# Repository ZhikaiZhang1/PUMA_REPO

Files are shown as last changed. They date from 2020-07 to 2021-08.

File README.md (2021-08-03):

# PUMA_REPO
6 dof robot arm with PD+Gravity control, matlab robot model includes inertia, coriolis and gravity matrix using E-L derivation
See playlist for robot in action and the progress so far:
https://www.youtube.com/watch?v=c_6ysLYgEvc&list=PL2PABLYC7PDOqciOI-CmroK_Q2sk5stWQ&index=1

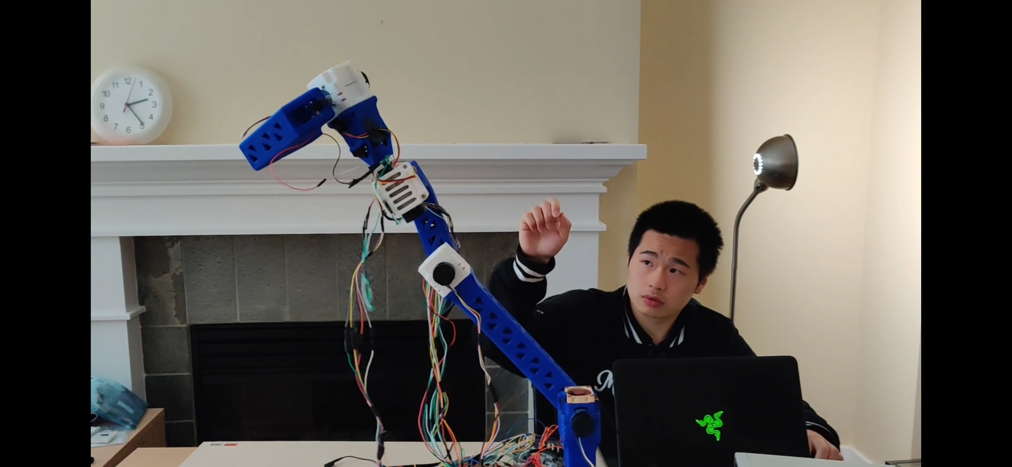
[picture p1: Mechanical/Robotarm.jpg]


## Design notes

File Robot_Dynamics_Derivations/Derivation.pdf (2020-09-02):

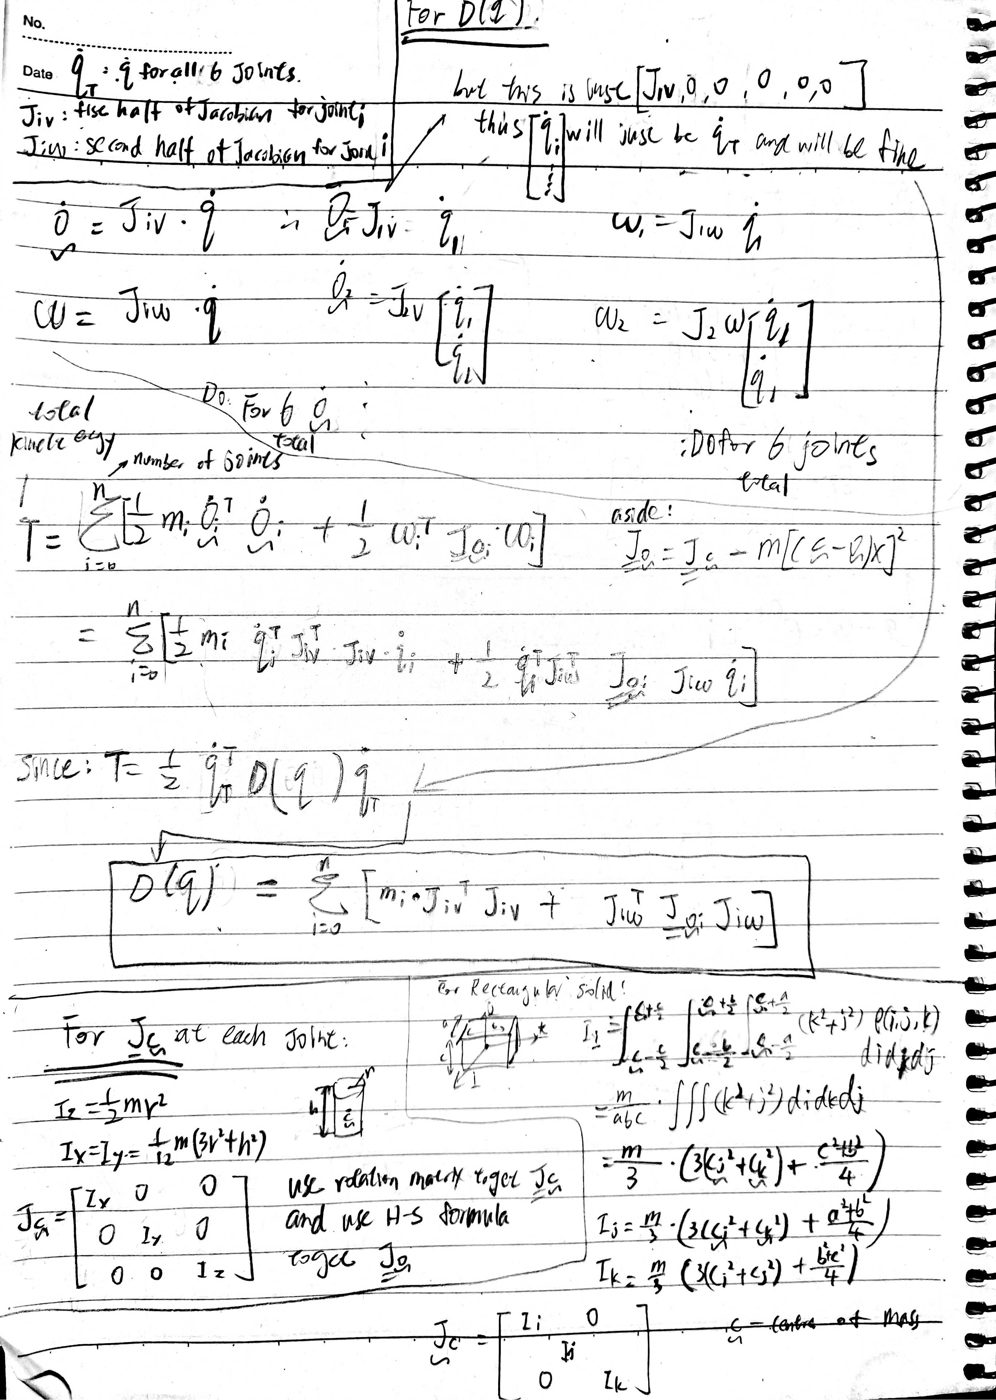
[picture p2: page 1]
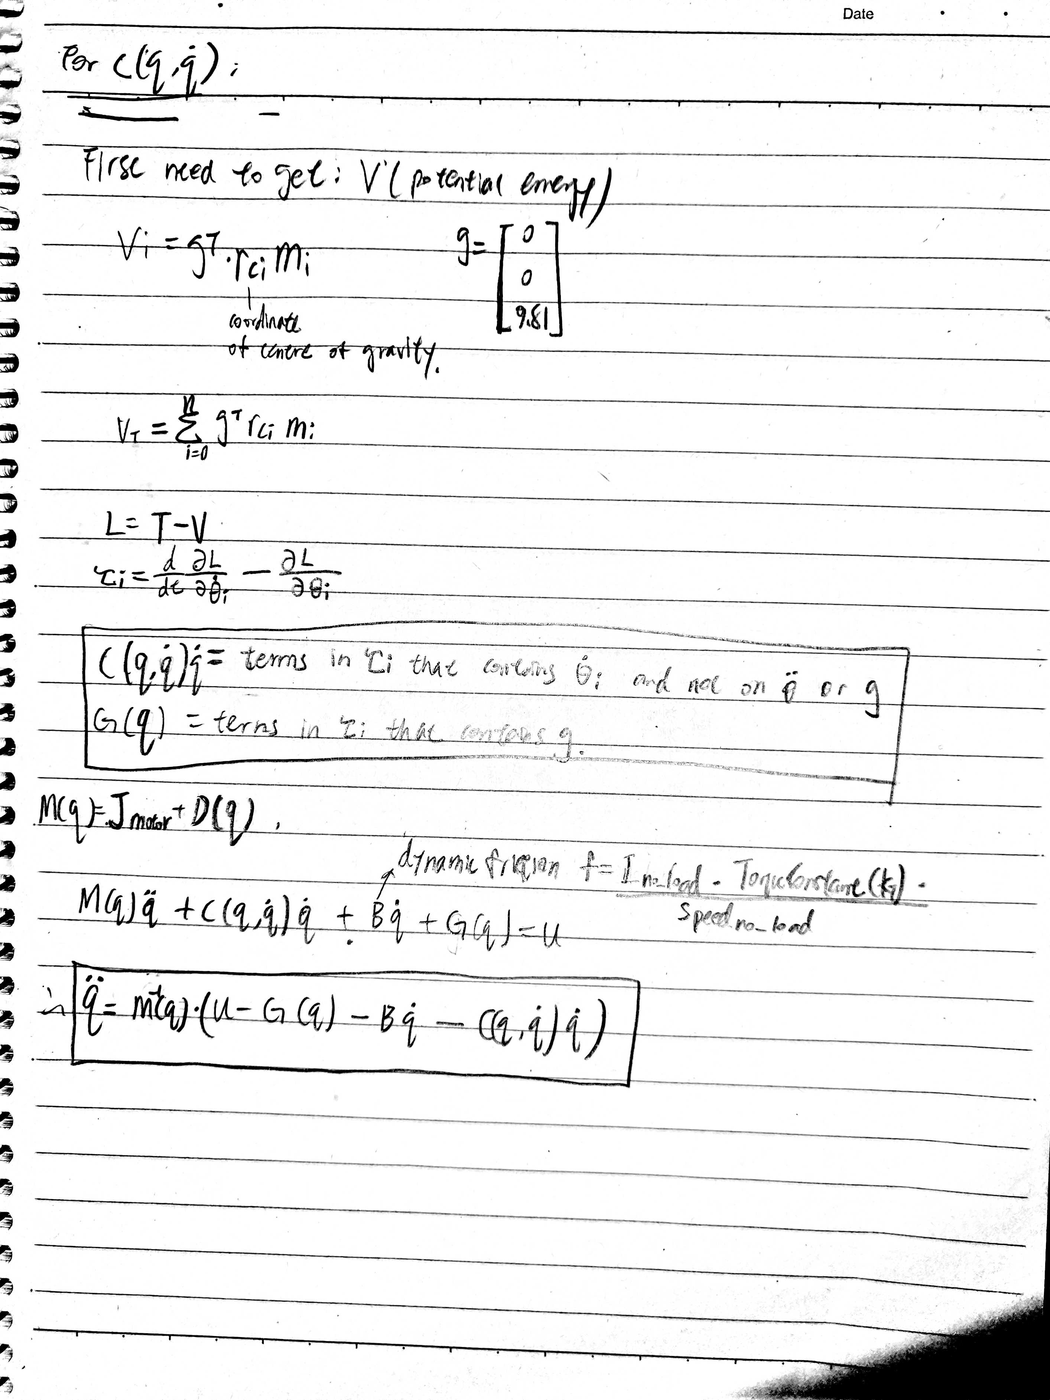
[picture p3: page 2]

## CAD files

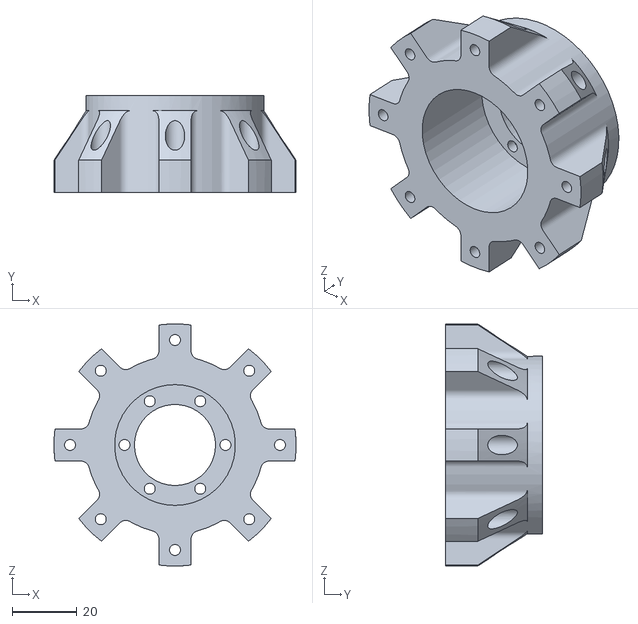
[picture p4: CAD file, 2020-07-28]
Mechanical/Motor_Mounting_Bracket_Top_2.STL
74.9 x 30.0 x 74.9

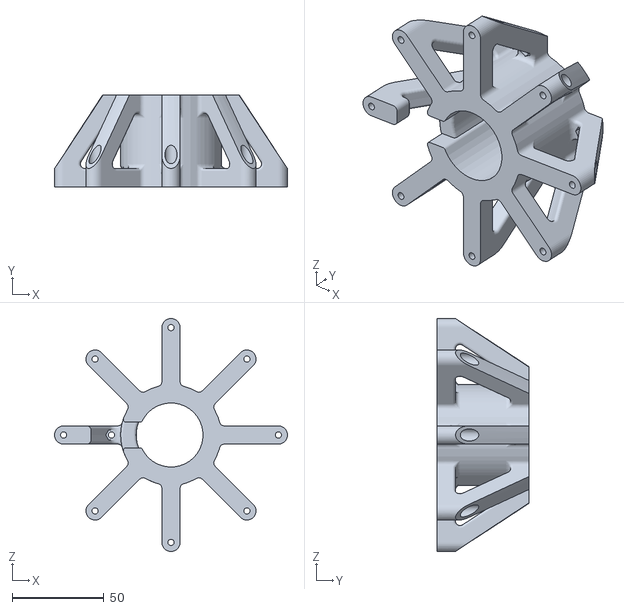
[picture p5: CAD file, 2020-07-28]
Mechanical/Motor_Mounting_Bracket_Bottom_2.STL
127.3 x 50.0 x 127.3

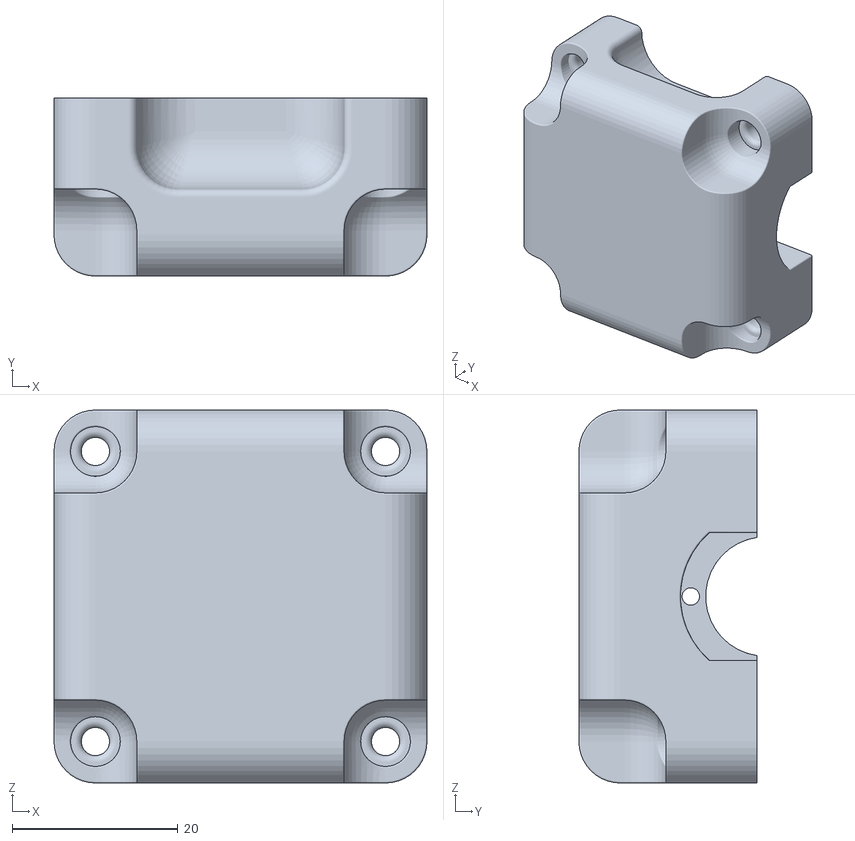
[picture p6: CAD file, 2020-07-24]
Mechanical/Arm 5 - Motor#6 Left.STL
45.0 x 21.5 x 45.0

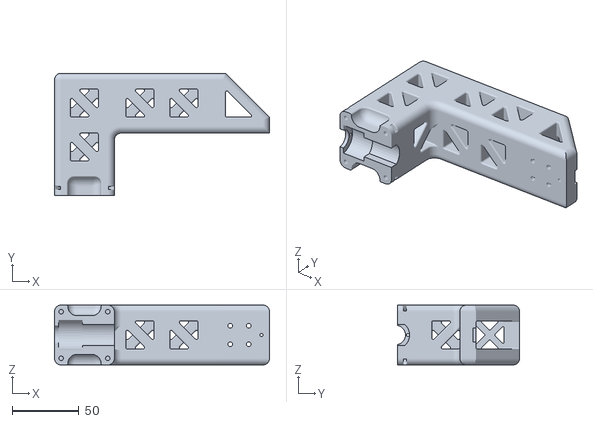
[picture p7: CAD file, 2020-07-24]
Mechanical/Arm 5 - Motor#6 Right.STL
161.5 x 92.0 x 45.0

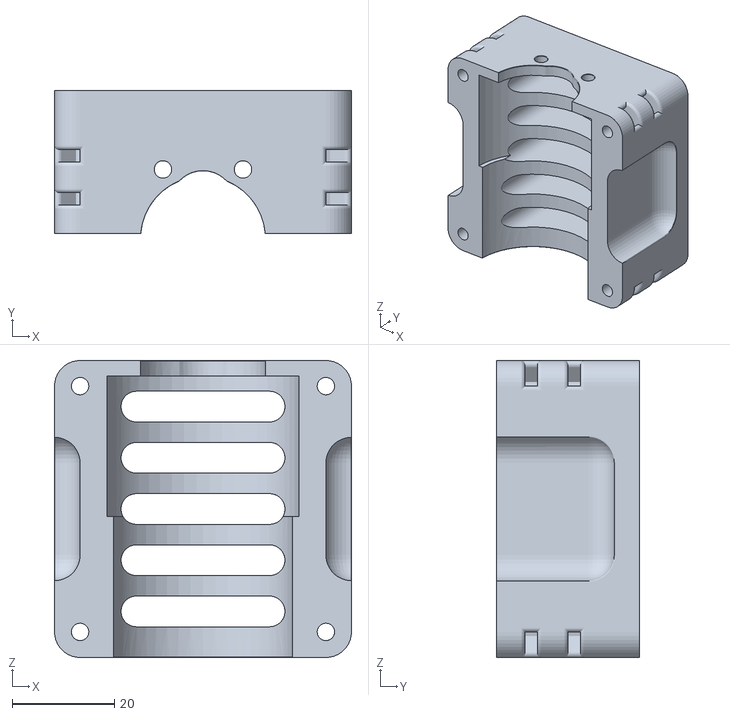
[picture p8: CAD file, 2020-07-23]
Mechanical/Motor Clamp 8.5 Bottom.STL
58.0 x 28.0 x 58.0

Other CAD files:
G_q_lib/G_q_initialize.obj
Puma_control/Core/Src/Glib/G_q_terminate.obj
G_q_lib/rtGetNaN.obj
Puma_control/Core/Src/Glib/rtGetNaN.obj
G_q_lib/G_q_terminate.obj
Puma_control/Core/Src/Glib/G_q.obj
G_q_lib/G_q_data.obj
Puma_control/Core/Src/Glib/G_q_data.obj
G_q_lib/G_q.obj
Puma_control/Core/Src/Glib/rtGetInf.obj
G_q_lib/rtGetInf.obj
Mechanical/Motor Clamp 8 Bottom.STL
Puma_control/Core/Src/Glib/G_q_initialize.obj
G_q_lib/exp.obj
G_q_lib/rt_nonfinite.obj
Mechanical/Arm 4.02.STL
Mechanical/Arm 4.STL
Mechanical/Clamp Test Bottom 1.STL
Mechanical/Clamp Test Bottom 2.STL
Mechanical/Clamp Test Bottom 3.STL
Mechanical/Clamp Test Top 1.STL
Mechanical/Clamp Test Top 2.STL
Mechanical/Clamp Test Top 3.STL
Mechanical/Hardware Test 1 Bottom.STL
Mechanical/Hardware Test 1 Top.STL
Mechanical/Hardware Test 2 Bottom.STL
Mechanical/Hardware Test 2 Top.STL
Mechanical/Hardware Test 3 Bottom.STL
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

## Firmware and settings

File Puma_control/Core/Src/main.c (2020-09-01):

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

/* Includes ------------------------------------------------------------------*/
#include "main.h"
#include "usb_device.h"

/* USER CODE BEGIN Includes */
#include <stdbool.h>
#include <stdio.h>
#include <string.h>
#include <stdlib.h>
#include "stm32h7xx_hal_uart.h"
#include "G_q.h"
#include "G_q_terminate.h"
#include "rt_nonfinite.h"

/* USER CODE END Includes */

/* USER CODE BEGIN PTD */
typedef struct PINS{
	GPIO_TypeDef* port;
	uint16_t  pin_num;
}PINS;

typedef struct HOME{
	double coords[6];
	bool home_set;
}HOME;

/* USER CODE END PTD */

/* USER CODE BEGIN PD */
#define HIGH 1U
#define LOW  0U
#define NUM_JOINTS 6
#define REV_COUNT_1 17280.0
#define REV_COUNT_2 5756.0
#define REV_COUNT_3 115.0 //assumed, may not be correct
#define G_CONSTANT 9.81
#define PI 3.1415926
const int K_P[] = {1500/(180/(3.1415926)), 3300/(180/(3.1415926)), 3200/(180/(3.1415926)), 800/(180/(3.1415926)), 1000/(180/(3.1415926)), 700};
const int K_V[] = {500/(180/(3.1415926)), 2000/(180/(3.1415926)), 1300/(180/(3.1415926)), 1300/(180/(3.1415926)), 500/(180/(3.1415926)), 600};
const double V_CONSTANT[] = {1.0456,1.0456,1.0456, 0.32,0.32, 0.00091};
const double T_CONSTANT[] = {1.307, 1.307, 1.307, 0.5324, 0.5324, 0.089240515};
const double RESISTANCE[] = {1.7, 1.7, 1.7, 5, 5, 5};
//const double test_pos[] = {3.1415926/2.0, 3.1415926/4.0, 3.1415926/3.0, 3.1415926/2.0, 3.1415926/5.0, 3.1415926};
const double test_pos[10][6] = {{0,-10,25,20,0,0},
							    {0,-20,35,30,0,0},
								{0,-30,45,40,0,0},
								{0,-40,55,50,0,0},
								{0,-50,45,60,0,0},
								{0,-60,55,50,0,0},
								{0,-40,55,40,0,0},
								{0,-30,45,30,0,0},
								{0,-20,35,20,0,0},
								{0,-20,25,10,0,0}};
//const double test_pos[] = {0,-3.1415926/3.0,0,0,0,0};
const double test_pos_2[] = {0,-3.1415926/3.0,0,0,0,0};
const double start_pos[] = {0, 0.9075, 0.9075, 0, 0, 0};
//for measuring CPU cycle
#define  ARM_CM_DEMCR      (*(uint32_t *)0xE000EDFC)

#define  ARM_CM_DWT_CTRL   (*(uint32_t *)0xE0001000)

#define  ARM_CM_DWT_CYCCNT (*(uint32_t *)0xE0001004)


/* USER CODE END PD */


TIM_HandleTypeDef htim1;
TIM_HandleTypeDef htim2;
TIM_HandleTypeDef htim3;
TIM_HandleTypeDef htim4;
TIM_HandleTypeDef htim5;
TIM_HandleTypeDef htim6;
TIM_HandleTypeDef htim7;

UART_HandleTypeDef huart1;
UART_HandleTypeDef huart3;

/* USER CODE BEGIN PV */
volatile int Lstate[6];
volatile int val_encoderB[6];
volatile int val_encoderA[6];
volatile int motor_steps[6] = {0};
volatile bool direction [6] = {true};
volatile bool need_control  = true;
volatile double joint_speed[6] = {0};
volatile int delta_pos [6] = {0};
volatile double current_angle[6] = {0};
double backemf [6] = {0};
volatile double desired_pos[6] = {0};
volatile int time_count = 0;
bool start_up = true;
bool homing_state [5] = {false};
bool start_state = true;

//pins: 0,1,2,3,4,7 - PA0(PA15), PA1(PD5), PB2(PA9), PE3(PE4), PD4(PD3), PD7(PE2)
// HAL_GPIO_ReadPin(GPIO_TypeDef *GPIOx, uint16_t GPIO_Pin)
PINS encoders[12];
//PE0, PF11, PG8, PG5, PF15, PE15, PG4, PE10, PE12, PD11, PD12, PD13
PINS Driver_P [6];
PINS Driver_N [6];

//Homing coords
HOME Homing;
/* USER CODE END PV */

void SystemClock_Config(void);
static void MX_GPIO_Init(void);
static void MX_USART3_UART_Init(void);
static void MX_TIM1_Init(void);
static void MX_TIM2_Init(void);
static void MX_TIM3_Init(void);
static void MX_TIM5_Init(void);
static void MX_USART1_UART_Init(void);
static void MX_TIM7_Init(void);
static void MX_TIM4_Init(void);
static void MX_TIM6_Init(void);
/* USER CODE BEGIN 0 */
extern uint8_t CDC_Transmit_FS(uint8_t* Buf, uint16_t Len);
//handle GPIO interrupt
void HAL_GPIO_EXTI_Callback(uint16_t GPIO_Pin)
{
	/*typedef struct PINS{
		GPIO_TypeDef* port;
		uint16_t  pin_num;
    }PINS;*/
	//encoder pins: 0,1,2,3,4,7 - PA0(PE5)y, PD1(PF6)y, PB2(PF8)y, PE3(PF9)y, PD4(PF10)y, PD7(PE2)y
	//homing pins: PE5, PF6, 8, 9, 10
	// HAL_GPIO_ReadPin(GPIO_TypeDef *GPIOx, uint16_t GPIO_Pin)
	switch (GPIO_Pin){
	case GPIO_PIN_0:
		if (val_encoderA[0] ^ val_encoderB[0]){
			motor_steps[0]++;
			delta_pos[0]++;
		}
		else{
			motor_steps[0]--;
			delta_pos[0]--;
		}
		val_encoderA[0] = HAL_GPIO_ReadPin(encoders[0].port, encoders[0].pin_num);
		/*
		 Lstate[0] = HAL_GPIO_ReadPin(encoders[0].port, encoders[0].pin_num);
		  if((val_encoderA[0] == LOW) && Lstate[0]==HIGH)
		  {
			val_encoderB[0] = HAL_GPIO_ReadPin(encoders[1].port, encoders[1].pin_num);
		    if(val_encoderB[0] == LOW && direction[0])
		    {
		      direction[0] = false; //Reverse
		    }
		    else if(val_encoderB[0] == HIGH && !direction[0])
		    {
		    	direction[0] = true;  //Forward
		    }
		  }
		  val_encoderA[0] = Lstate[0];

		  if(!direction[0]){
			  motor_steps[0]++;
			  delta_pos[0]++;
		  }
		  else{
			  motor_steps[0]--;
			  delta_pos[0]--;
		  }*/
		break;
	case GPIO_PIN_5:
		val_encoderB[0] = HAL_GPIO_ReadPin(encoders[1].port, encoders[1].pin_num);
		if (val_encoderA[0] ^ val_encoderB[0]){
			motor_steps[0]++;
			delta_pos[0]++;
		}
		else{
			motor_steps[0]--;
			delta_pos[0]--;

		}
		break;


	case GPIO_PIN_1:
		if (val_encoderA[1] ^ val_encoderB[1]){
			motor_steps[1]++;
			delta_pos[1]++;
		}
		else{
			motor_steps[1]--;
			delta_pos[1]--;
		}
		val_encoderA[1] = HAL_GPIO_ReadPin(encoders[2].port, encoders[2].pin_num);
		break;
	case GPIO_PIN_6:
		val_encoderB[1] = HAL_GPIO_ReadPin(encoders[3].port, encoders[3].pin_num);
		if (val_encoderA[1] ^ val_encoderB[1]){
			motor_steps[1]++;
			delta_pos[1]++;
		}
		else{
			motor_steps[1]--;
			delta_pos[1]--;
		}
		break;
	case GPIO_PIN_2:
		if (val_encoderA[2] ^ val_encoderB[2]){
			motor_steps[2]++;
			delta_pos[2]++;
		}
		else{
			motor_steps[2]--;
			delta_pos[2]--;
		}
		val_encoderA[2] = HAL_GPIO_ReadPin(encoders[4].port, encoders[4].pin_num);
		break;
	case GPIO_PIN_8:
		val_encoderB[2] = HAL_GPIO_ReadPin(encoders[5].port, encoders[5].pin_num);
		if (val_encoderA[2] ^ val_encoderB[2]){
			motor_steps[2]++;
			delta_pos[2]++;
		}
		else{
			motor_steps[2]--;
			delta_pos[2]--;
		}
		break;
	case GPIO_PIN_3:
		if (val_encoderA[3] ^ val_encoderB[3]){
			motor_steps[3]++;
			delta_pos[3]++;
		}
		else{
			motor_steps[3]--;
			delta_pos[3]--;
		}
		val_encoderA[3] = HAL_GPIO_ReadPin(encoders[6].port, encoders[6].pin_num);
		break;
	case GPIO_PIN_9:
		val_encoderB[3] = HAL_GPIO_ReadPin(encoders[7].port, encoders[7].pin_num);
		if (val_encoderA[3] ^ val_encoderB[3]){
			motor_steps[3]++;
			delta_pos[3]++;
		}
		else{
			motor_steps[3]--;
			delta_pos[3]--;
		}
		break;
	case GPIO_PIN_4:
		if (val_encoderA[4] ^ val_encoderB[4]){
			motor_steps[4]++;
			delta_pos[4]++;
		}
		else{
			motor_steps[4]--;
			delta_pos[4]--;
		}
		val_encoderA[4] = HAL_GPIO_ReadPin(encoders[8].port, encoders[8].pin_num);
		break;
	case GPIO_PIN_7:
		val_encoderB[4] = HAL_GPIO_ReadPin(encoders[9].port, encoders[9].pin_num);
		if (val_encoderA[4] ^ val_encoderB[4]){
			motor_steps[4]++;
			delta_pos[4]++;
		}
		else{
			motor_steps[4]--;
			delta_pos[4]--;
		}
		break;

	/*case GPIO_PIN_5:
		//desired_pos[0] = (double)motor_steps[0] *2.0*3.1415926/REV_COUNT_1*2.0;
		homing_state[0] = true;
		break;
	case GPIO_PIN_6:
		//desired_pos[1] = (double)motor_steps[1] *2.0*3.1415926/REV_COUNT_1*2.0;
		homing_state[1] = true;
		break;
	case GPIO_PIN_8:
		//desired_pos[2] = (double)motor_steps[2] *2.0*3.1415926/REV_COUNT_1*2.0;
		homing_state[2] = true;
		break;
	case GPIO_PIN_9:
		//desired_pos[3] = (double)motor_steps[3] *2.0*3.1415926/REV_COUNT_2*2.0;
		homing_state[3] = true;
		break;
	case GPIO_PIN_10:
		//desired_pos[4] = (double)motor_steps[4] *2.0*3.1415926/REV_COUNT_2*2.0;
		homing_state[4] = true;
		break;*/
	default:
		break;
	}
}

void set_up_encoder_pins(void){
	//old pins: 0,1,2,3,4,7 - PA0(PC10)y, PD1(PD5)y, PB2(PC7)y, PE3(PE4)y, PD4(PD3)y, PD7(PE2)y
	//new encoder pins: 0,1,2,3,4,7 - PA0(PE5)y, PD1(PF6)y, PB2(PF8)y, PE3(PF9)y, PD4(PF10)y, PD7(PE2)y
	// HAL_GPIO_ReadPin(GPIO_TypeDef *GPIOx, uint16_t GPIO_Pin)
	encoders[0].port = GPIOA; encoders[0].pin_num = GPIO_PIN_0;
	encoders[1].port = GPIOE; encoders[1].pin_num = GPIO_PIN_5;
	encoders[2].port = GPIOD; encoders[2].pin_num = GPIO_PIN_1;
	encoders[3].port = GPIOF; encoders[3].pin_num = GPIO_PIN_6;
	encoders[4].port = GPIOB; encoders[4].pin_num = GPIO_PIN_2;
	encoders[5].port = GPIOF; encoders[5].pin_num = GPIO_PIN_8;
	encoders[6].port = GPIOE; encoders[6].pin_num = GPIO_PIN_3;
	encoders[7].port = GPIOF; encoders[7].pin_num = GPIO_PIN_9;
	encoders[8].port = GPIOA; encoders[8].pin_num = GPIO_PIN_4;
	encoders[9].port = GPIOD; encoders[9].pin_num = GPIO_PIN_7;
	encoders[10].port = GPIOD; encoders[10].pin_num = GPIO_PIN_7;
    encoders[11].port = GPIOE; encoders[11].pin_num = GPIO_PIN_3;
}
void set_up_driver_pins(void){
	//PE0, PF11, PG8, PG5, PF15, PD10, PG4, PE10, PE12, PD11, PD12, PD13
	Driver_P[0].port = GPIOE; Driver_P[0].pin_num = GPIO_PIN_0;
	Driver_N[0].port = GPIOF; Driver_N[0].pin_num = GPIO_PIN_11;
	Driver_P[1].port = GPIOG; Driver_P[1].pin_num = GPIO_PIN_8;
	Driver_N[1].port = GPIOG; Driver_N[1].pin_num = GPIO_PIN_5;
	Driver_P[2].port = GPIOF; Driver_P[2].pin_num = GPIO_PIN_15;
	Driver_N[2].port = GPIOA; Driver_N[2].pin_num = GPIO_PIN_2;
	Driver_P[3].port = GPIOG; Driver_P[3].pin_num = GPIO_PIN_4;
	Driver_N[3].port = GPIOE; Driver_N[3].pin_num = GPIO_PIN_10;
	Driver_P[4].port = GPIOE; Driver_P[4].pin_num = GPIO_PIN_12;
	Driver_N[4].port = GPIOD; Driver_N[4].pin_num = GPIO_PIN_11;
	Driver_P[5].port = GPIOD; Driver_P[5].pin_num = GPIO_PIN_12;
	Driver_N[5].port = GPIOD; Driver_N[5].pin_num = GPIO_PIN_13;
}

void PWM3_change_duty_cycle (int valuePA6, int valuePB1, int valuePA7){
	TIM_OC_InitTypeDef sConfigOC = {0};
	sConfigOC.OCMode = TIM_OCMODE_PWM1;
	  sConfigOC.Pulse = valuePA6;
	  sConfigOC.OCPolarity = TIM_OCPOLARITY_HIGH;
	  sConfigOC.OCFastMode = TIM_OCFAST_DISABLE;
	  if (HAL_TIM_PWM_ConfigChannel(&htim3, &sConfigOC, TIM_CHANNEL_1) != HAL_OK)
	  {
	    Error_Handler();
	  }
	  /*sConfigOC.Pulse = valuePB0;
	  if (HAL_TIM_PWM_ConfigChannel(&htim3, &sConfigOC, TIM_CHANNEL_3) != HAL_OK)
	  {
	    Error_Handler();
	  }*/
	  sConfigOC.Pulse = valuePB1;
	  if (HAL_TIM_PWM_ConfigChannel(&htim3, &sConfigOC, TIM_CHANNEL_4) != HAL_OK)
	  {
	    Error_Handler();
	  }
	  sConfigOC.Pulse = valuePA7;
	  if (HAL_TIM_PWM_ConfigChannel(&htim3, &sConfigOC, TIM_CHANNEL_2) != HAL_OK)
	  	  {
	  	    Error_Handler();
	  	  }
	  HAL_TIM_PWM_Start(&htim3, TIM_CHANNEL_1);
	  HAL_TIM_PWM_Start(&htim3, TIM_CHANNEL_2);
	  HAL_TIM_PWM_Start(&htim3, TIM_CHANNEL_4);
}
void PWM1_change_duty_cycle (int valuePE11, int valuePE13){
	TIM_OC_InitTypeDef sConfigOC = {0};
	sConfigOC.OCMode = TIM_OCMODE_PWM1;
	  sConfigOC.Pulse = valuePE11;
	  sConfigOC.OCPolarity = TIM_OCPOLARITY_HIGH;
	  sConfigOC.OCNPolarity = TIM_OCNPOLARITY_HIGH;
	  sConfigOC.OCFastMode = TIM_OCFAST_DISABLE;
	  sConfigOC.OCIdleState = TIM_OCIDLESTATE_RESET;
	  sConfigOC.OCNIdleState = TIM_OCNIDLESTATE_RESET;
	  if (HAL_TIM_PWM_ConfigChannel(&htim1, &sConfigOC, TIM_CHANNEL_2) != HAL_OK)
	  {
	    Error_Handler();
	  }
	  sConfigOC.Pulse = valuePE13;
	  if (HAL_TIM_PWM_ConfigChannel(&htim1, &sConfigOC, TIM_CHANNEL_3) != HAL_OK)
	  {
	    Error_Handler();
	  }
	  HAL_TIM_PWM_Start(&htim1, TIM_CHANNEL_2);
	  HAL_TIM_PWM_Start(&htim1, TIM_CHANNEL_3);
}

//pin PA5
void PWM2_change_duty_cycle (int valuePA5){
	TIM_OC_InitTypeDef sConfigOC = {0};
	sConfigOC.OCMode = TIM_OCMODE_PWM1;
    sConfigOC.Pulse = valuePA5;
	sConfigOC.OCPolarity = TIM_OCPOLARITY_HIGH;
	sConfigOC.OCFastMode = TIM_OCFAST_DISABLE;
	if (HAL_TIM_PWM_ConfigChannel(&htim2, &sConfigOC, TIM_CHANNEL_1) != HAL_OK)
	{
	  Error_Handler();
    }
	HAL_TIM_PWM_Start(&htim2, TIM_CHANNEL_1);
}
#ifdef __GNUC__
/* With GCC/RAISONANCE, small printf (option LD Linker->Libraries->Small printf
   set to 'Yes') calls __io_putchar() */
#define PUTCHAR_PROTOTYPE int __io_putchar(int ch)
#else
#define PUTCHAR_PROTOTYPE int fputc(int ch, FILE *f)
#endif /* __GNUC__ */
PUTCHAR_PROTOTYPE
{
  /* Place your implementation of fputc here */
  /* e.g. write a character to the USART1 and Loop until the end of transmission */
  //HAL_UART_Transmit(&UartHandle, (uint8_t *)&ch, 1, 0xFFFF);
  CDC_Transmit_FS((uint8_t *)&ch, 1);
  return ch;
}

void HAL_TIM_PeriodElapsedCallback(TIM_HandleTypeDef *htim){
	int j;
	if (htim == &htim7){
		for (j = 0; j < NUM_JOINTS; j++){

			if (j <3){
				current_angle[j] = (double)motor_steps[j] *2.0*3.1415926/REV_COUNT_1;
				//current_angle[j] = current_angle[j] + (double)delta_pos[j] *2.0*3.1415926/REV_COUNT_1/0.01*2.0;
				joint_speed[j] = (double)delta_pos[j] *2.0*3.1415926/REV_COUNT_1/0.01;
			}
			else if (j < 5){
				current_angle[j] = (double)motor_steps[j] *2.0*3.1415926/REV_COUNT_2;
				//current_angle[j] = current_angle[j] + (double)delta_pos[j] *2.0*3.1415926/REV_COUNT_2/0.01*2.0;
				joint_speed[j] = (double)delta_pos[j] *2.0*3.1415926/REV_COUNT_2/0.01;
			}
			else{
				current_angle[j] = (double)motor_steps[j] *2.0*3.1415926/REV_COUNT_3;
				//current_angle[j] = current_angle[j] + (double)delta_pos[j] *2.0*3.1415926/REV_COUNT_3/0.01*2.0;
				joint_speed[j] = (double)delta_pos[j] *2.0*3.1415926/REV_COUNT_3/0.01;
			}
			delta_pos[j] = 0;
		}

		need_control = true;
	}
	else{
		time_count ++;
	}
}

void brake_motor(int motor_index){
	HAL_GPIO_WritePin(Driver_P[motor_index].port, Driver_P[motor_index].pin_num, 0);
	HAL_GPIO_WritePin(Driver_N[motor_index].port, Driver_N[motor_index].pin_num, 0);
}

void Joint_controller(bool homing, creal_T* G_q_vector, volatile double* joint_speed){
	int k;
	int PWM_val [6] = {0};
	double G_q_r [6] = {0};
	double angle_diff[6] = {0};
	double current_deg[6] = {0};
	double prev_desired[6] = {0};
	int num_rows = sizeof(test_pos)/sizeof(test_pos[0]);
	int dir[6] = {0};
	double desired_diff;
	int x = 0;
	G_q(G_CONSTANT, current_angle[2], current_angle[3], current_angle[4], current_angle[5], G_q_vector);
	for (k = 0; k < NUM_JOINTS; k++){
		//set duty cycle with PD+Gravity control
		G_q_r[k] = (double)G_q_vector[k].re;
		backemf[k] = joint_speed[k] * V_CONSTANT[k];
		G_q_r[k] *= 1024;
		G_q_r[k] /= (12.0 - backemf[k])/RESISTANCE[k];//*T_CONSTANT[k];
		current_deg[k] = current_angle[k]*180/(3.1415926);
		angle_diff[k] = desired_pos[k] - current_deg[k];
		desired_diff = abs((int)(desired_pos[k] - prev_desired[k]))*0.1;
		if (abs((int)angle_diff[k]) <= abs((int)(desired_pos[k] - prev_desired[k]))*0.3){
			for (x = 0; x < num_rows; x++){
				if (desired_pos[k] == test_pos[x][k]){
					break;
				}
			}
			if (x < num_rows-1){
				prev_desired[k] = desired_pos[k];
				desired_pos[k] = test_pos[x+1][k];
			}
		}
		PWM_val[k] = G_q_r[k] + K_P[k] * (angle_diff[k]) - K_V[k] * joint_speed[k];
		if (PWM_val[k] > 1024){
			PWM_val[k] = 1024;
			dir[k] = 1;
		}
		else if (PWM_val[k] < -1024){
			PWM_val[k] = -1024;
		}

		//set directions

		if (PWM_val[k] < 0){
			HAL_GPIO_WritePin(Driver_P[k].port, Driver_P[k].pin_num, 0);
			HAL_GPIO_WritePin(Driver_N[k].port, Driver_N[k].pin_num, 1);
			//HAL_GPIO_WritePin(Driver_N[k].port, Driver_N[k].pin_num, 1);
			PWM_val[k] = 0-PWM_val[k];
		}
		else if (PWM_val[k] > 0){
			HAL_GPIO_WritePin(Driver_P[k].port, Driver_P[k].pin_num, 1);
			HAL_GPIO_WritePin(Driver_N[k].port, Driver_N[k].pin_num, 0);
		}
		else{
			HAL_GPIO_WritePin(Driver_P[k].port, Driver_P[k].pin_num, 0);
			HAL_GPIO_WritePin(Driver_N[k].port, Driver_N[k].pin_num, 0);
		}

	}
	//PWM1_change_duty_cycle(PWM_val[0], PWM_val[1]);
	//PWM1_change_duty_cycle(PWM_val[0], PWM_val[1]);
	//PWM2_change_duty_cycle(PWM_val[2]);
	//PWM3_change_duty_cycle(PWM_val[3], PWM_val[4], PWM_val[5]);
		PWM3_change_duty_cycle(0, PWM_val[1], PWM_val[2]);
		PWM1_change_duty_cycle(PWM_val[3],PWM_val[4]);// PWM_val[4]);
		PWM2_change_duty_cycle(0);
}

void homing (void){
	//start_state = false;
	// need to set to false, don't forget
	/*int g = 0;
	for (g = 0; g < NUM_JOINTS; g++){
		current_angle[g] = 0;
		motor_steps[g] = 0;
	}*/
	//after everything is finished for homing it will set all coords to 0

	start_state = false;

}
void StartUp(void){
	//set directions
	HAL_GPIO_WritePin(Driver_P[0].port, Driver_P[0].pin_num, 0);
	HAL_GPIO_WritePin(Driver_N[0].port, Driver_N[0].pin_num, 1);
	HAL_GPIO_WritePin(Driver_P[1].port, Driver_P[1].pin_num, 0);
	HAL_GPIO_WritePin(Driver_N[1].port, Driver_N[1].pin_num, 1);
	HAL_GPIO_WritePin(Driver_P[2].port, Driver_P[2].pin_num, 0);
	HAL_GPIO_WritePin(Driver_N[2].port, Driver_N[2].pin_num, 1);
	HAL_GPIO_WritePin(Driver_P[3].port, Driver_P[3].pin_num, 0);
	HAL_GPIO_WritePin(Driver_N[3].port, Driver_N[3].pin_num, 1);
	HAL_GPIO_WritePin(Driver_P[4].port, Driver_P[4].pin_num, 1);
	HAL_GPIO_WritePin(Driver_N[4].port, Driver_N[4].pin_num, 0);
	HAL_GPIO_WritePin(Driver_P[5].port, Driver_P[5].pin_num, 0);
	HAL_GPIO_WritePin(Driver_N[5].port, Driver_N[5].pin_num, 1);

	//spin motors
	PWM3_change_duty_cycle(0, 750, 400);
	PWM1_change_duty_cycle(500, 500);
	PWM2_change_duty_cycle(0);

}

/* USER CODE END 0 */

/**
  * @brief  The application entry point.
  * @retval int
  */
int main(void)
{
  /* USER CODE BEGIN 1 */
	char* msg = "Hello Nucleo Fun!\n\r";
	char* EOL = "]\n\r";
	char* EOJ = ", ";
	char* timer_tester = "timed\n\r";
	char one_motor[10];
	char print_string[60];
	int i;
	uint32_t  start;
	uint32_t  stop;
	uint32_t  delta;
	creal_T G_q_vector[6];
	int flag_1 = 1;

	//setting up pins
	set_up_encoder_pins();
	set_up_driver_pins();

    for(i = 0; i < NUM_JOINTS; i++){
    	val_encoderA [i] = HIGH;
    	val_encoderB [i] = HIGH;
    	direction [i] = true;
    	desired_pos[i] = test_pos[0][i];
    	current_angle[i] = start_pos[i];
    	motor_steps[i] = start_pos[i]/(2.0*3.1415926/REV_COUNT_1*2.0);
    	motor_steps[i] = start_pos[i]/(2.0*3.1415926/REV_COUNT_1*2.0);
    }

    Homing.home_set = false;
    //for CPU cycle counts
    if (ARM_CM_DWT_CTRL != 0) {        // See if DWT is available

        ARM_CM_DEMCR      |= 1 << 24;  // Set bit 24

        ARM_CM_DWT_CYCCNT  = 0;

        ARM_CM_DWT_CTRL   |= 1 << 0;   // Set bit 0

    }

  /* USER CODE END 1 */

  /* MCU Configuration--------------------------------------------------------*/

  /* Reset of all peripherals, Initializes the Flash interface and the Systick. */
  HAL_Init();

  /* Configure the system clock */
  SystemClock_Config();

  /* Initialize all configured peripherals */
  MX_GPIO_Init();
  MX_USART3_UART_Init();
  MX_TIM1_Init();
  MX_TIM2_Init();
  MX_TIM3_Init();
  MX_TIM5_Init();
  MX_USART1_UART_Init();
  MX_USB_DEVICE_Init();
  MX_TIM7_Init();
  MX_TIM4_Init();
  MX_TIM6_Init();
  /* USER CODE BEGIN 2 */
  //PWM3_change_duty_cycle(1024, 500, 100);
  /* USER CODE END 2 */

  /* Infinite loop */
  /* USER CODE BEGIN WHILE */
  while (1)
  {
    /* USER CODE END WHILE */

    /* USER CODE BEGIN 3 */
	  /*start_up = !(homing_state[0] && homing_state[1] && homing_state[2] && homing_state[3] && homing_state[4]) && start_state;
	  Homing.home_set = (homing_state[0] && homing_state[1] && homing_state[2] && homing_state[3] && homing_state[4]) && start_state;
	  if (Homing.home_set){
		  homing();

	  }
	  else if (start_up){
		  StartUp();

	  }*/
	  //printf(msg);
	  if (HAL_GPIO_ReadPin(GPIOC, GPIO_PIN_13)){
		  itoa(motor_steps[0], one_motor, 10);
		  strcpy(print_string, one_motor);
		  for (i = 1; i < NUM_JOINTS; i++){
			  //current_angle[i]*180/(2*3.1415926)
			  //itoa(motor_steps[i], one_motor, 20);
			  sprintf(one_motor,"%f", current_angle[i]*180/(3.1415926));
			  strcat(print_string, EOJ);
			  strcat(print_string, one_motor);
		  }
		  strcat(print_string, EOL);
		  CDC_Transmit_FS((uint8_t*)"motor is at [", strlen(msg));
		  HAL_Delay(2);
		  CDC_Transmit_FS((uint8_t*)print_string, strlen(print_string));
		  HAL_Delay(2);
	  }
	  if (need_control){
		  start = ARM_CM_DWT_CYCCNT;
		  Joint_controller(false, G_q_vector, joint_speed);
		  stop  = ARM_CM_DWT_CYCCNT;
		  delta = stop - start;
		  need_control = false;
		  //CDC_Transmit_FS((uint8_t*)timer_tester, strlen(timer_tester));
		  //HAL_Delay(1);
	  }
	  //desired_pos[i] = test_pos[0][i];
	  if (time_count >= 50 && flag_1 == 1){
		  flag_1 = 0;
		  for(i = 0; i < NUM_JOINTS; i++){
		      desired_pos[i] = test_pos_2[i]*180/(3.1415926);
		      }

	  }

	  //HAL_UART_Transmit(&huart1, (uint8_t*)msg, strlen(msg), 100);
	  //CDC_Transmit_FS(msg, sizeof(msg));
  }
  G_q_terminate();
  /* USER CODE END 3 */
}

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


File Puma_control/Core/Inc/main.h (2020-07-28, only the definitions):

#define MCO_Pin GPIO_PIN_0
#define MCO_GPIO_Port GPIOH
#define RMII_MDIO_Pin GPIO_PIN_2
#define RMII_MDIO_GPIO_Port GPIOA
#define RMII_RXD0_Pin GPIO_PIN_4
#define RMII_RXD0_GPIO_Port GPIOC
#define RMII_RXD1_Pin GPIO_PIN_5
#define RMII_RXD1_GPIO_Port GPIOC
#define RMII_TXD1_Pin GPIO_PIN_13
#define RMII_TXD1_GPIO_Port GPIOB
#define LD3_Pin GPIO_PIN_14
#define LD3_GPIO_Port GPIOB
#define STLK_RX_Pin GPIO_PIN_8
#define STLK_RX_GPIO_Port GPIOD
#define STLK_TX_Pin GPIO_PIN_9
#define STLK_TX_GPIO_Port GPIOD
#define USB_PowerSwitchOn_Pin GPIO_PIN_6
#define USB_PowerSwitchOn_GPIO_Port GPIOG
#define USB_OverCurrent_Pin GPIO_PIN_7
#define USB_OverCurrent_GPIO_Port GPIOG
#define USB_SOF_Pin GPIO_PIN_8
#define USB_SOF_GPIO_Port GPIOA
#define USB_ID_Pin GPIO_PIN_10
#define USB_ID_GPIO_Port GPIOA
#define USB_DM_Pin GPIO_PIN_11
#define USB_DM_GPIO_Port GPIOA
#define USB_DP_Pin GPIO_PIN_12
#define USB_DP_GPIO_Port GPIOA
#define RMII_TX_EN_Pin GPIO_PIN_11
#define RMII_TX_EN_GPIO_Port GPIOG
#define RMII_TXD0_Pin GPIO_PIN_13
#define RMII_TXD0_GPIO_Port GPIOG
#define LD2_Pin GPIO_PIN_7
#define LD2_GPIO_Port GPIOB

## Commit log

2020-05-19 Test Print FIles
    Square/Round friction and tolerance test.
    [Round Test Female 5.SLDPRT, Round Test Male.SLDPRT, Square Test Female.SLDPRT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]
2020-05-19 STL print files for Square/Round tests
    [Round Test Female 5.STL, Round Test Male.STL, Square Test Female.STL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]
2020-05-25 Hardware Test 1 Files
    [Hardware Test 1 Bottom.STL, Hardware Test 1 Top.STL]
2020-05-25 Hardware Test 2 Files
    Changed tolerances
    [Hardware Test 2 Bottom.STL, Hardware Test 2 Top.STL]
2020-05-25 Hardware Test 3 Files
    Removed stabilizing pegs
    [Hardware Test 3 Bottom.STL, Hardware Test 3 Top.STL]
2020-05-25 Link Design Test
    Shortened Link 1
    [Link 2.STL]
2020-05-31 Clamp Test 1
    [Clamp Test Bottom 1.STL, Clamp Test Top 1.STL]
2020-05-31 Clamp Test 2 Files
    Increased diameter of the through hole, tightened clamp radius.
    [Clamp Test Bottom 2.STL, Clamp Test Top 2.STL]
2020-06-03 Clamp Test 3 Files
    [Clamp Test Bottom 3.STL, Clamp Test Top 3.STL]
2020-06-04 Motor Housing V5 Files
    [Motor Clamp 5 Bottom.STL, Motor Clamp 5 Top.STL]
2020-06-04 Shaft Coupler Test 1 File
    [Motor Shaft Coupler Test 1.STL]
2020-06-16 Link Test Print
    [Link 3.STL]
2020-06-16 Link Test 2
    [Link 4.STL]
2020-06-23 Link Test 5
    [Link 5.STL]
2020-06-30 two methods of encoder reading conflicting, timer interrupt not working yet
    [Puma Debug.cfg]
2020-06-30 changing to one pin interrupt encoder method
2020-06-30 Timer7 interrupt working
2020-07-01 Adding backemf, Gravity matrix lib generated from matlab, and some minor changes
    [G_q.obj, G_q_data.obj, G_q_initialize.obj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]
2020-07-01 adding PWM
2020-07-02 Motor Housing V7.5 & Link V7.5(base)
    [Link 7.5.STL, Motor Clamp 7.5 Bottom.STL]
2020-07-04 Tolerance test for the shaft coupler connector
    [Link 7.5-180.STL, Link 7.5-90.STL]
2020-07-06 adding basic homing
2020-07-06 Arm between 2nd and 3rd
    Test Print
2020-07-07 Arm between 4th and 5th motor
    [Arm 4.STL]
2020-07-10 Arm 4 w/ Sensor Platform
    [Arm 4.02.STL]
2020-07-13 fixing dependencies
    [G_q.obj, G_q_data.obj, G_q_initialize.obj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]
2020-07-14 Motor Mounting Bracket V1
    [Motor Mounting Bracket Bottom.STL, Motor Mounting Bracket Top.STL]
2020-07-17 Arm between 3rd and 4th motor
2020-07-17 Arm 3.2
    Added mount for sensor
2020-07-20 New Motor Housings
    Added screw holes
    [Motor Clamp 8 Bottom.STL, Motor Clamp 8 Top.STL, Motor Mounting Bracket Top 2.STL]
2020-07-23 Motor Clamp 8.5 Bottom
    Added cutout for the lip around the drive shaft
    [Motor Clamp 8.5 Bottom.STL]
2020-07-24 5th Arm w/ 6th Motor
    [Arm 5 - Motor#6 Left.STL, Arm 5 - Motor#6 Right.STL]
2020-07-28 fixing flashing issue
    [G_q.obj, G_q_data.obj, G_q_initialize.obj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]
2020-07-28 Removing unnecessary files for git and adding two base mounting components
    [Motor_Mounting_Bracket_Bottom_2.STL, Motor_Mounting_Bracket_Top_2.STL]
2020-08-10 changing G_lib files, and some encoder changes
    [G_q.obj, G_q_data.obj, G_q_initialize.obj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]
2020-09-01 Updated Glib
    [G_q.obj, G_q_data.obj, G_q_initialize.obj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]

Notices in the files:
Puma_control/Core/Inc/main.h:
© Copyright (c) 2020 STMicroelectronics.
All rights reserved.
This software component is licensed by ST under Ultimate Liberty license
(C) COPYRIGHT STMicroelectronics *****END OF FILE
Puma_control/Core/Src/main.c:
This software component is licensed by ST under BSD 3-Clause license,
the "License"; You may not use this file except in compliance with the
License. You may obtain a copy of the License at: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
